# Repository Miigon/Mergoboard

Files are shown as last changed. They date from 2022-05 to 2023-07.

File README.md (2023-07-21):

# Mergoboard

38-key split ergonomic keyboard made with #ergogen.
## Note
This project is heavily based on [samoklava](https://github.com/soundmonster/samoklava) and uses much of the same footprints.
All the additional footprints or modified footprints are in the `footprints` folder.

## Screenshot
### rev0 (2022-05-02)
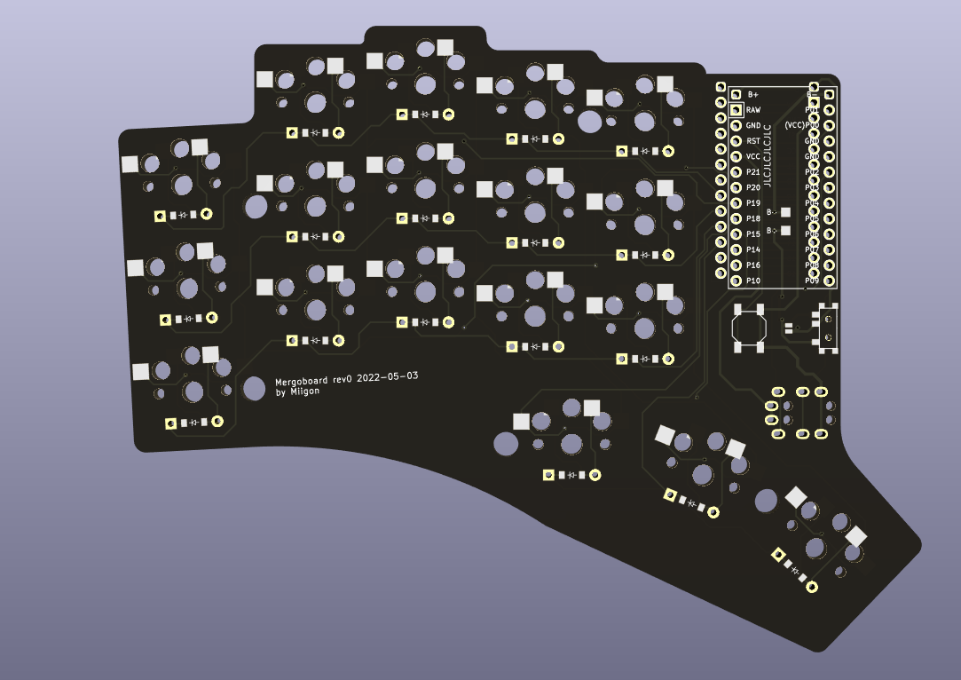
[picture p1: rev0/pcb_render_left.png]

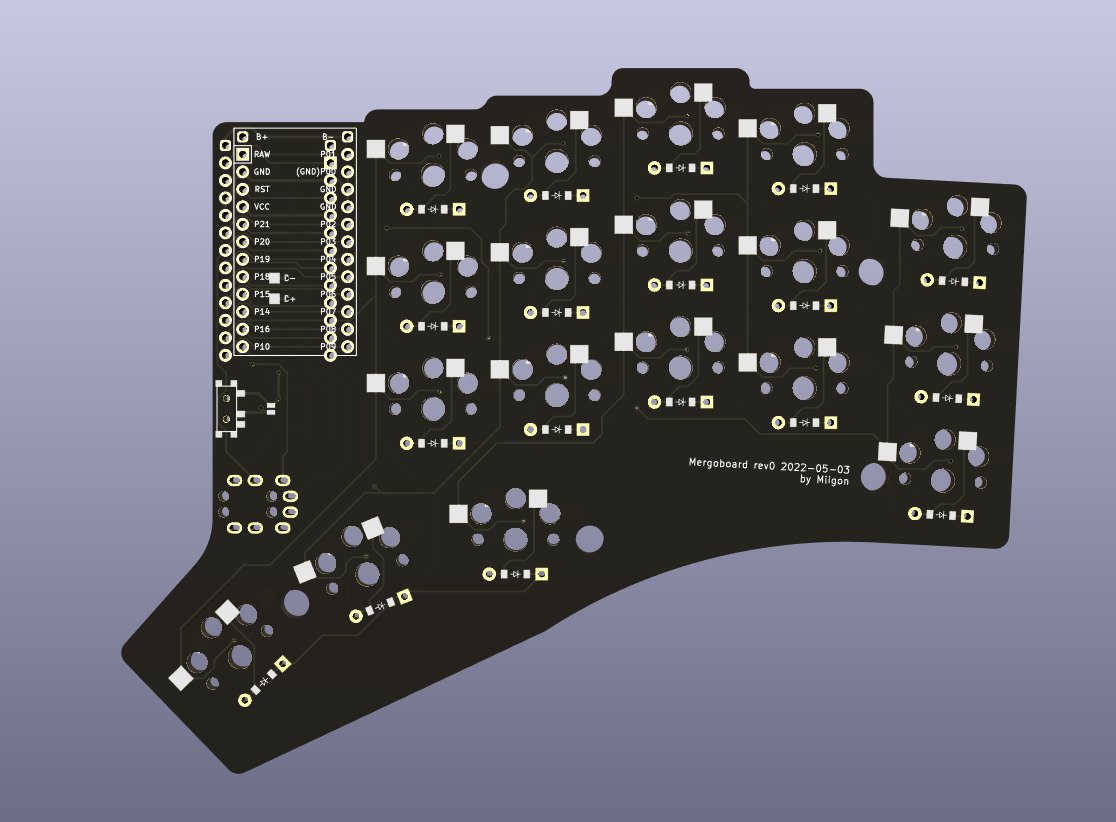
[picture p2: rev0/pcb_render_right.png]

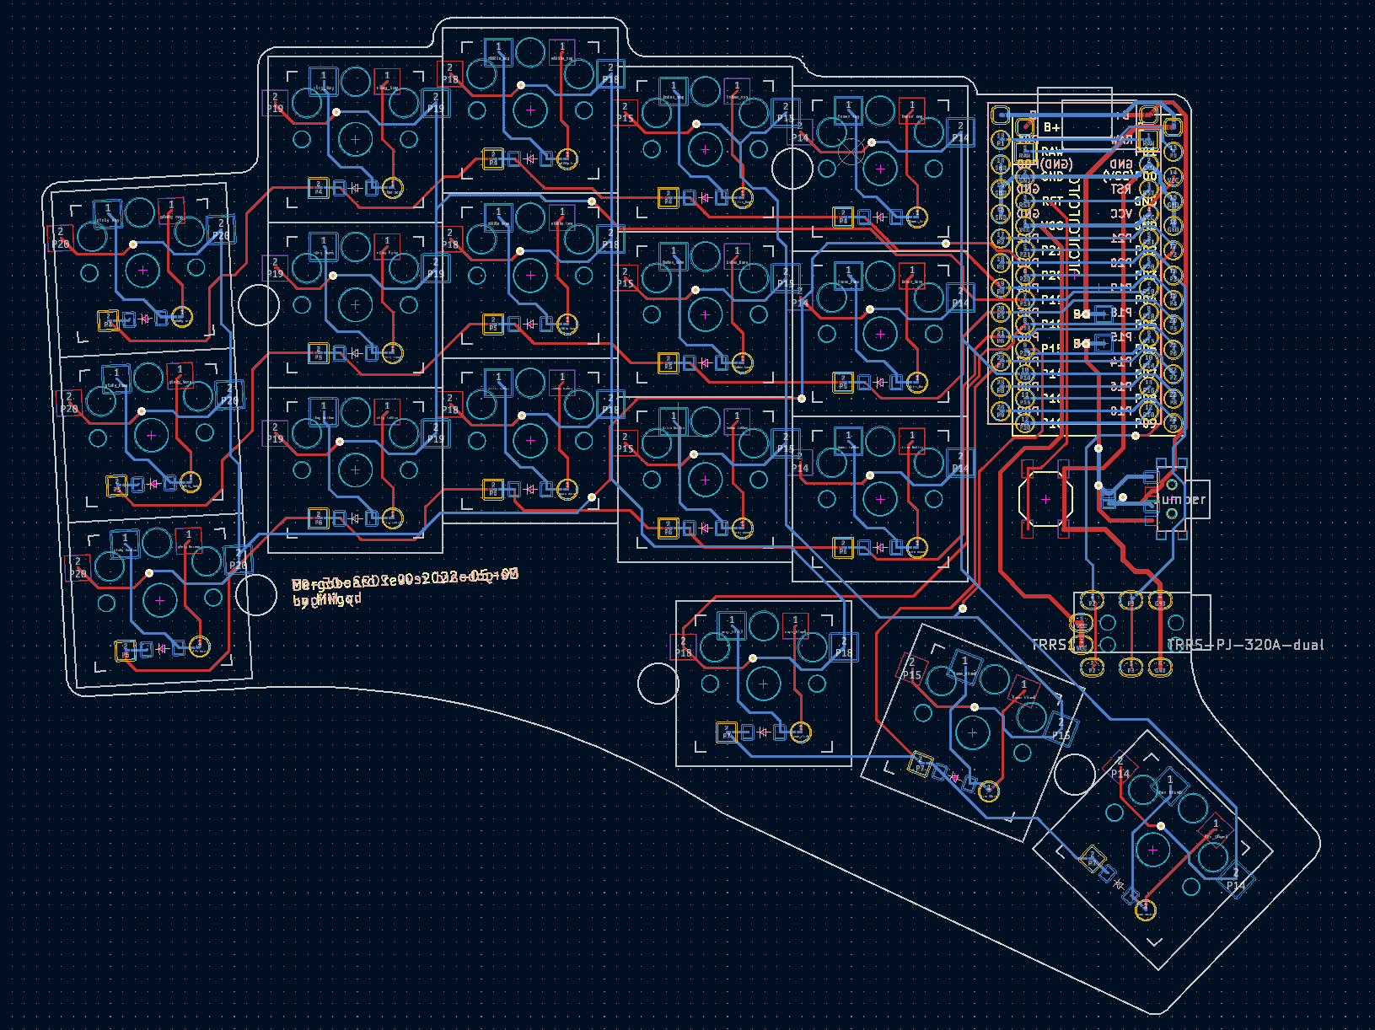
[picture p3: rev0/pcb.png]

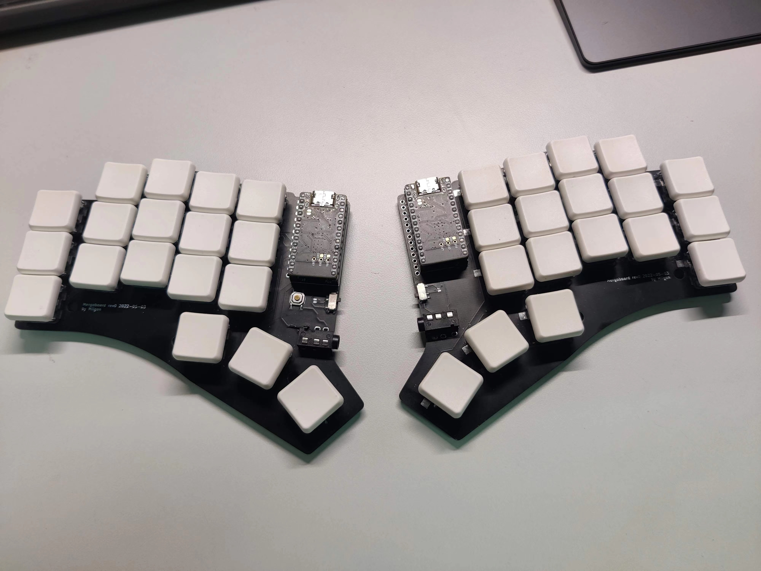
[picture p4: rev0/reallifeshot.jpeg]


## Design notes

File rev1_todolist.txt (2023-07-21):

1. fix trrs connector bug (rev0 incorrectly connected vcc to sleeve)
2. move B+ and B- pads out so that mcu sockets could be thinner
3. trrs connector footprint stabilizers should be 1.2 instead of 1.5
4. move mounting holes around to avoid obstructing switches
5. (maybe) use another mcu footprint that uses jumpers to support flipping
6. change the battery power switch so both halves are all on or off when the switch is in the same position
	(currently it results in one being on and another being off, which is confusing )
7. shrink the mounting holes a little bit (currently way larger than a M3 screw could ever need.)
8. make reset switch flippable so it's on the top side of the board on both hands. (or bottom for a cleaner look?) 
9. carry RAW instead of VCC through TRRS cable

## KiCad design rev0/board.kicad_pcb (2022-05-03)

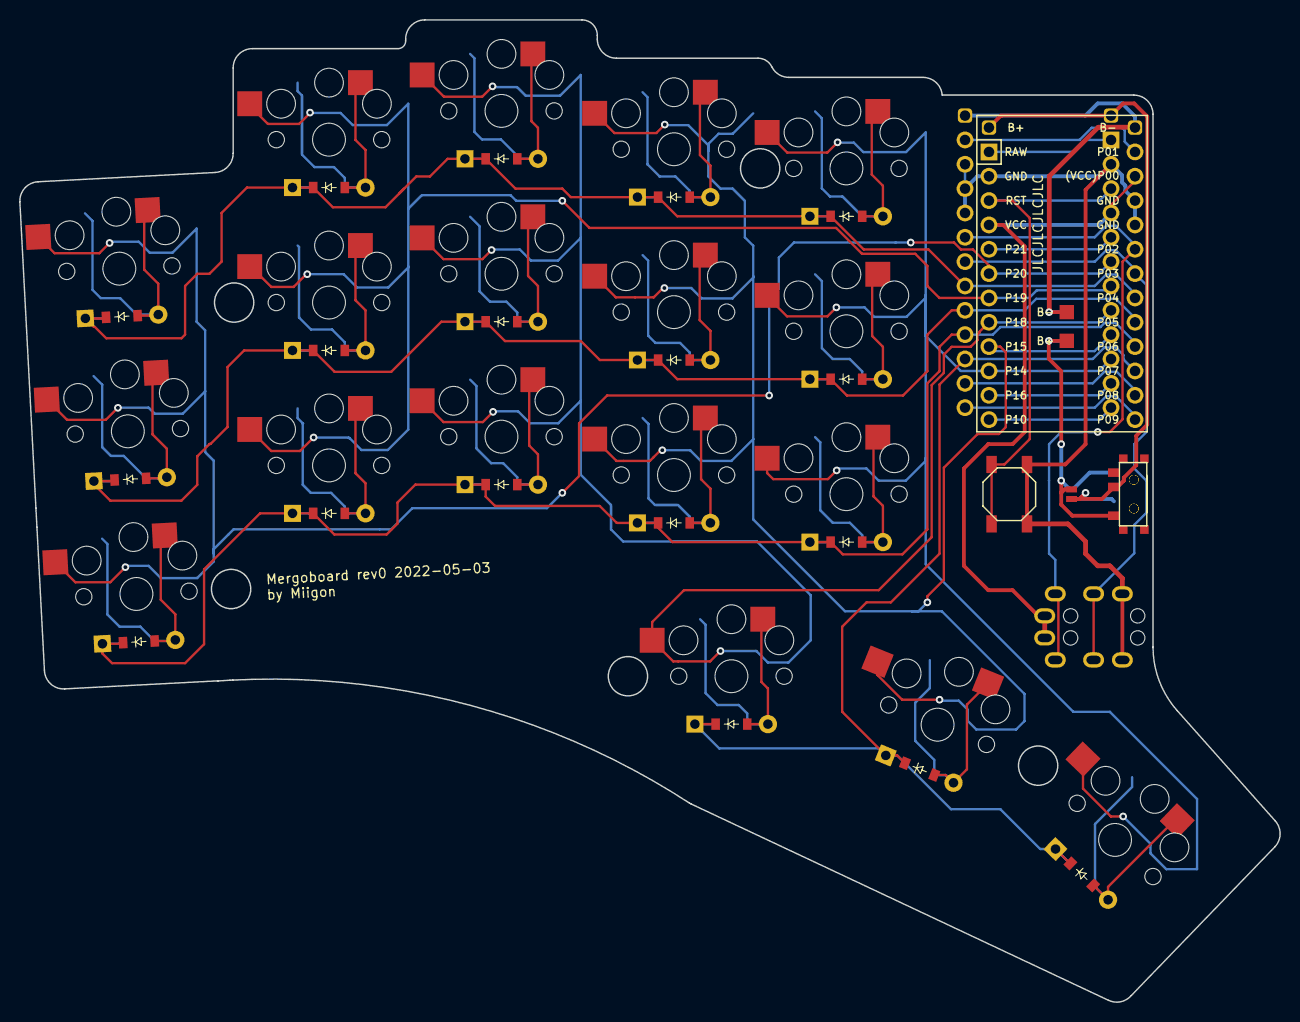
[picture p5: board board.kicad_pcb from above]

Board: 2 copper layers, 131.5 x 102.5 mm, 46 parts (0 on the bottom side), 42 nets.

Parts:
B1: SW_TACT_ALPS_SKQGABE010
D1, D2, D3, D4, D5, D6, D7, D8, D9, D10, D11, D12, D13, D14, D15, D16, D17, D18: ComboDiode
J1, J2: Jumper
MCU1, MCU2: ProMicro
PAD1, PAD2: SMDPad
S1, S2, S3, S4, S5, S6, S7, S8, S9, S10, S11, S12, S13, S14, S15, S16, S17, S18: PG1350
T1, T2: SPDT_C128955
TRRS1: TRRS-PJ-320A-dual

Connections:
Bminus: MCU1.25, MCU2.25, PAD2.1
Bplus: J1.2, J2.2, MCU1.25, MCU2.25, T1.2, T2.2
Braw: J1.1, J2.1, PAD1.1, T1.1, T2.1
GND: B1.1, MCU1.2, MCU1.14, MCU1.15, MCU1.16, MCU2.2, MCU2.15, MCU2.16, TRRS1.4
P1: MCU1.13, MCU2.13
P2: MCU1.17, MCU2.17, TRRS1.2
P3: MCU1.18, MCU2.18, TRRS1.3
P4: D3.1, D3.2, D6.1, D6.2, D9.1, D9.2, D12.1, D12.2, D15.1, D15.2, MCU1.19, MCU2.19
P5: D2.1, D2.2, D5.1, D5.2, D8.1, D8.2, D11.1, D11.2, D14.1, D14.2, MCU1.20, MCU2.20
P6: D1.1, D1.2, D4.1, D4.2, D7.1, D7.2, D10.1, D10.2, D13.1, D13.2, MCU1.21, MCU2.21
P7: D16.1, D16.2, D17.1, D17.2, D18.1, D18.2, MCU1.22, MCU2.22
P8: MCU1.23, MCU2.23
P9: MCU1.24, MCU2.24
P10: MCU1.12, MCU2.12
P14: MCU1.10, MCU2.10, S13.2, S14.2, S15.2, S18.2
P15: MCU1.9, MCU2.9, S10.2, S11.2, S12.2, S17.2
P16: MCU1.11, MCU2.11
P18: MCU1.8, MCU2.8, S7.2, S8.2, S9.2, S16.2
P19: MCU1.7, MCU2.7, S4.2, S5.2, S6.2
P20: MCU1.6, MCU2.6, S1.2, S2.2, S3.2
P21: MCU1.5, MCU2.5
RAW: MCU1.1, MCU2.1
RST: B1.2, MCU1.3, MCU2.3
VCC: MCU1.4, MCU2.4, MCU2.14, TRRS1.1
far_thumb: D18.1, D18.2, S18.1
home_thumb: D17.1, D17.2, S17.1
index_bottom: D10.1, D10.2, S10.1
index_home: D11.1, D11.2, S11.1
index_top: D12.1, D12.2, S12.1
inner_bottom: D13.1, D13.2, S13.1
inner_home: D14.1, D14.2, S14.1
inner_top: D15.1, D15.2, S15.1
middle_bottom: D7.1, D7.2, S7.1
middle_home: D8.1, D8.2, S8.1
middle_top: D9.1, D9.2, S9.1
near_thumb: D16.1, D16.2, S16.1
pinky_bottom: D1.1, D1.2, S1.1
pinky_home: D2.1, D2.2, S2.1
pinky_top: D3.1, D3.2, S3.1
ring_bottom: D4.1, D4.2, S4.1
ring_home: D5.1, D5.2, S5.1
ring_top: D6.1, D6.2, S6.1

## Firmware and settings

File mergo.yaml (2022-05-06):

units:
  kx: cx
  ky: cy
  px: 2
  py: 2
points:
  key:
    footprints:
      choc_hotswap:
        type: choc
        params:
          hotswap: true
          reverse: true
          keycaps: true
        nets:
          # from: P1
          # to: P2
          from: =colrow
          to: =column_net
      diode:
        type: diode
        nets:
          # from: P3
          # to: P4
          from: =colrow
          to: =row_net
        anchor:
          shift: [0, -5]
  zones:
    matrix:
      #anchor:
         #rotate: 0
      key.padding: ky
      columns:
        pinky:
          stagger: 0 ky
          spread: kx
          rotate: 3
          key:
            column_net: P20
        ring:
          rotate: -3
          origin: [-12, -19]
          stagger: 13
          spread: 1.1kx
          key:
            column_net: P19
        middle:
          stagger: 3
          spread: kx
          key:
            column_net: P18
        index:
          stagger: -4
          spread: kx
          key:
            column_net: P15
        inner:
          stagger: -2.0
          spread: kx
          key:
            column_net: P14
      rows:
        bottom:
          row_net: P6
        home:
          row_net: P5
        top:
          row_net: P4
    thumbfan:
      anchor:
        ref: matrix_inner_bottom
        shift: [-12, -19]
      columns:
        near:
          key:
            column_net: P18
        home:
          spread: 19
          rotate: -22
          origin: [-11.75, -9]
          key:
            column_net: P15
        far:
          spread: 19
          rotate: -22
          origin: [-9.5, -9]
          key:
            column_net: P14
      rows:
        thumb:
          row_net: P7
outlines:
  # board dimensions according to JLCPCB: 13.15cm x 10.25cm
  exports:
    raw:
      - type: keys
        side: left
        size: [kx + px, ky + py]
    _thumbfan_glue_polygon:
      - type: polygon
        points:
          - ref: matrix_inner_bottom
            shift: [0.5 kx + 0.5px, -0 ky + 2.5 py]
          - ref: thumbfan_far_thumb
            shift: [0.75 kx - 0.5px, 0.70 ky + 0.5 py]
          - ref: thumbfan_far_thumb
            shift: [0.75 kx - 0.5px, -0.65 ky - 0.5 py]
          - ref: thumbfan_near_thumb
            shift: [-0.3 kx + 0.5 px, -0.72 ky - 0.5 py]
          - ref: matrix_pinky_bottom
            shift: [0.5 kx - 0.5 py, -0.5 ky - 0.5 py]
          - ref: matrix_pinky_bottom
            shift: [0 kx - 0.5 py, -0.5 ky - 0.5 py]
          - ref: matrix_pinky_home
            shift: [-0.5 kx , 0]
          - ref: matrix_inner_home
            shift: [0.5 kx + 0.5px, -0.5 ky + 0.5 py]
    thumbfan_glue:
      polygon:
        type: outline
        name: _thumbfan_glue_polygon
      sub_circle:
       type: circle
       radius: 80
       anchor:
         - ref: thumbfan_near_thumb
           shift: [0 kx - 24 px, -0.5 ky - 35.9 py]
       operation: subtract
        
        
    patch_outer:
      - type: polygon
        points:
          - ref: matrix_pinky_top
            shift: [1.5 (kx + px), 0.5 (ky + py)]
          - ref: matrix_ring_bottom
          - ref: matrix_pinky_bottom
            shift: [0.5 (kx + px), -0 (ky + py)]
          - ref: matrix_pinky_top
            shift: [0.5 (kx + px), 0.5 (ky + py)]
    controller_area:
      main:
        type: rectangle
        anchor:
          ref:
            - matrix_inner_top
          shift: [0 kx, -4.05 ky]
        size: [32, 76.5]
        corner: px
    switches:
      main:
        type: keys
        side: left
        size: 14
        bound: false
    keycaps:
      main:
        type: keys
        side: left
        size: [kx, ky]
        bound: false
        corner: 1
    _keywell:
      main:
        type: outline
        name: raw
      patch_outer:
        type: outline
        name: patch_outer
        operation: add
      thumbfan_glue:
        type: outline
        name: thumbfan_glue
        operation: add
        #fillet: 5px
    _keywell_fillet_pass1:
        - type: outline
          name: _keywell
          fillet: px
    _keywell_fillet_pass2:
        - type: outline
          name: _keywell_fillet_pass1
          fillet: 0.8px
    _keywell_fillet_pass3:
        - type: outline
          name: _keywell_fillet_pass2
          fillet: 0.4px
    keywell:
      main:
        type: outline
        name: _keywell_fillet_pass3
    _base_outline:
      main:
        type: outline
        name: keywell
      controller:
        type: outline
        name: controller_area
        operation: add
    base_outline:
        - type: outline
          name: _base_outline
          fillet: 5px
    screw_holes:
      top_left:
        type: circle
        anchor:
          - ref: matrix_ring_home
            shift: [-0.55 kx, 0 ky]
        radius: 1.05
      bottom_left:
        type: circle
        anchor:
          - ref: matrix_pinky_bottom
            shift: [0.55 kx, 0]
        radius: 1.05
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

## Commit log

2022-05-03 README, footprints and images
    [board-B_Cu.gbr, board-B_Mask.gbr, board-B_Paste.gbr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]
2022-05-06 rev1 start: fix TRRS connection (previously VCC on sleeve)
    [mergo.yaml]
